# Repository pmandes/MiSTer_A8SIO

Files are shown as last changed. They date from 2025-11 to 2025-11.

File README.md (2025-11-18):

# MiSTer_A8SIO
Adapter for the SIO port to connect peripheral devices of the 8-bit Atari to the MiSTer FPGA.

## Interactive BOM: ##

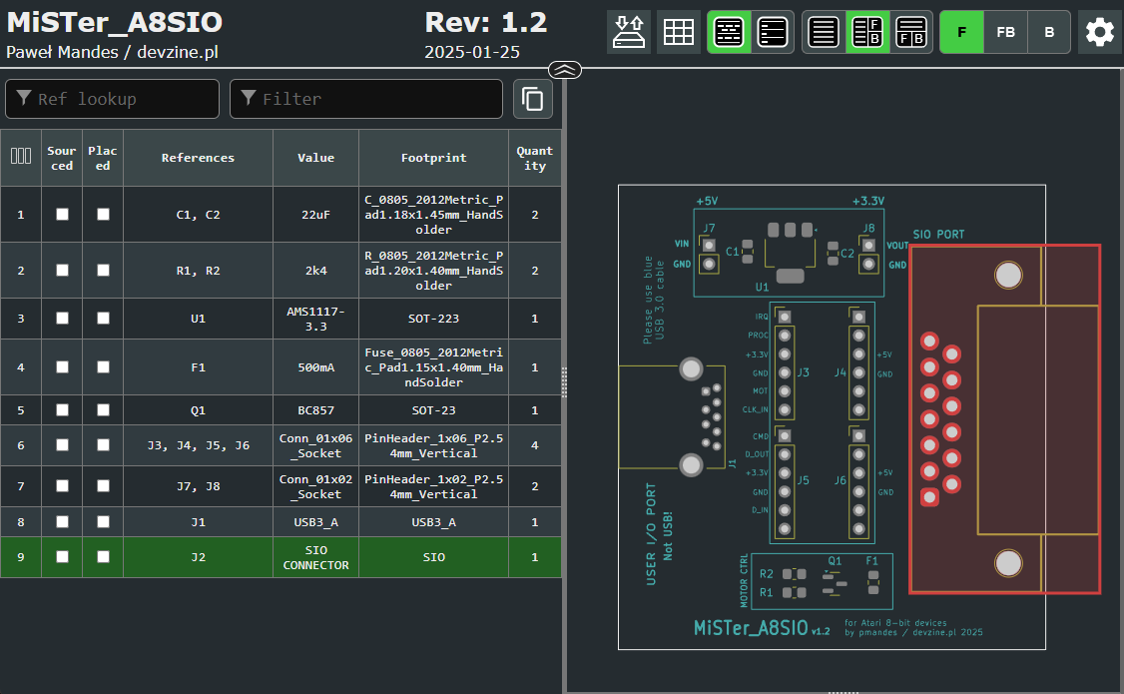
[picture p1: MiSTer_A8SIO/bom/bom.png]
<p align="center"></p>

## Components ##

The following modules can be used to build an adapter without using SMD components:

- AMS 1117 3.3V stabiliser module
- 2 x 4ch level shifter module
- USB 3.0 Type A angled socket
- SIO socket

<p align="center">
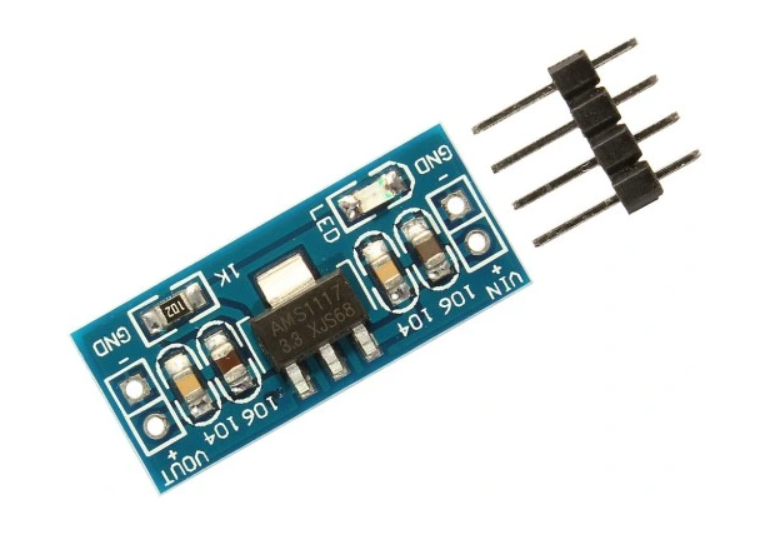
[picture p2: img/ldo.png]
  
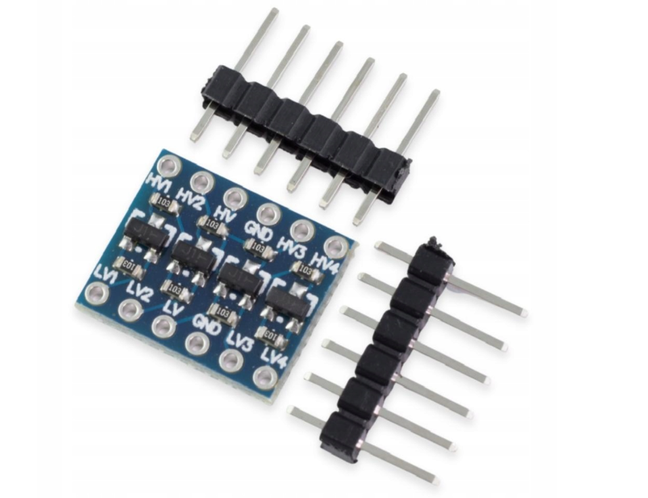
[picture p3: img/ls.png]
  
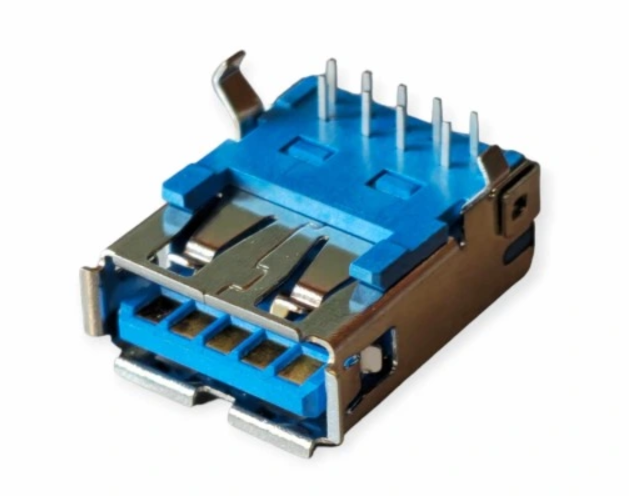
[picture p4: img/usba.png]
  
</p>

For basic functionality, one level shifter (mounted on J5/J6) and an LDO power supply module (mounted on J7/J8) are sufficient.

The MOTOR CTRL circuit for controlling the tape recorder is optional.

**To connect to MisterFPGA, you need a USB3.0 A data transfer cable (blue type A plugs on both sides).**

**The adapter can ONLY be connected to the User Port on the I/O daughter board.**

## Prototype ##

The prototype was tested with the following equipment:
- Atari 1050 Floppy disk drive
- FujiNet network adapter
- SDriveMAX drive emulator

<p align="center">
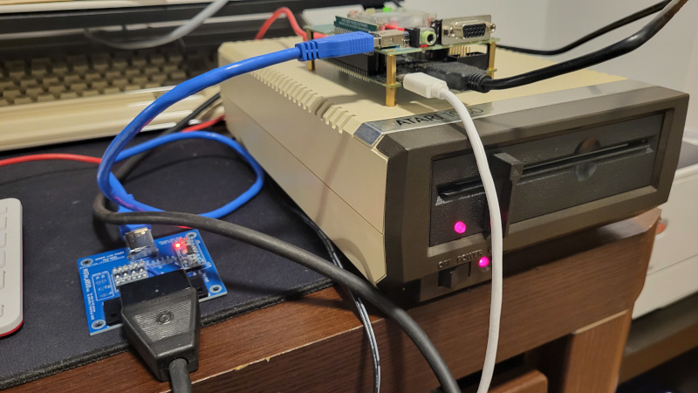
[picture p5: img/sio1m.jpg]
  
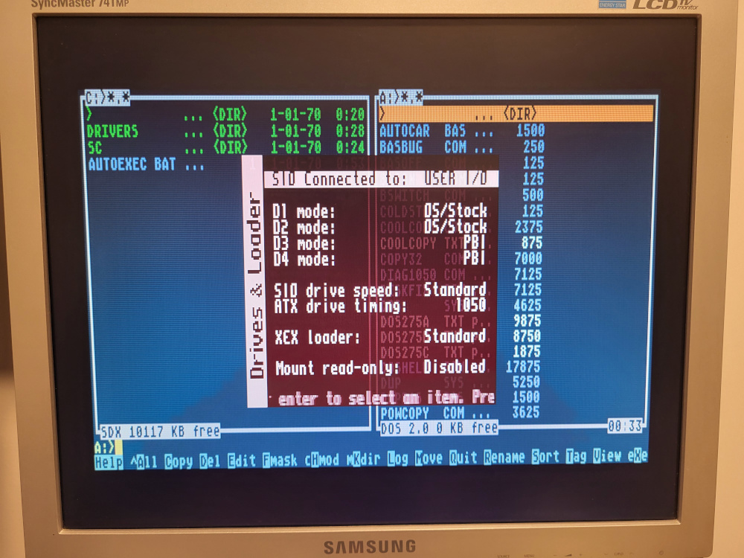
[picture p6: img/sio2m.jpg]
  
</p>
<p align="center">
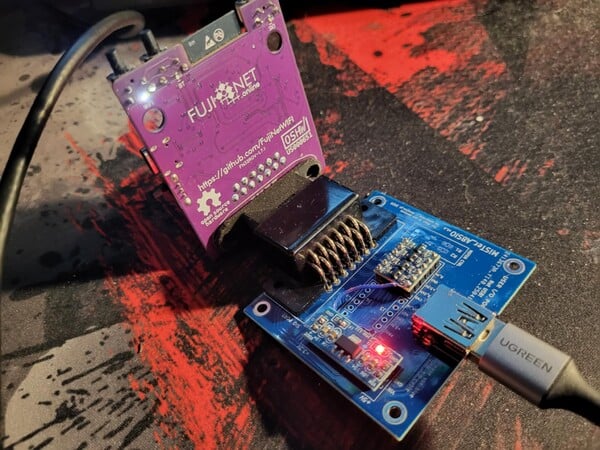
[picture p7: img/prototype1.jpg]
  
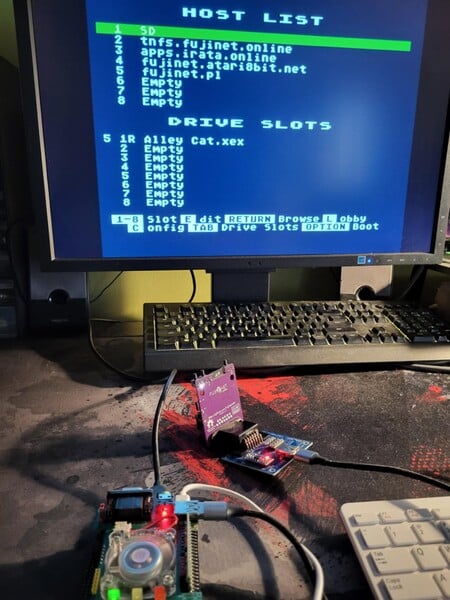
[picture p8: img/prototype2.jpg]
  
</p>

## Changleog: ##

**1.2**
- fix: crossed lines from USB3 A-A cable

**1.1**
- prototype / not published
- 2 * 4ch level shifters modules instead of HW221
  
**1.0**
- initial project

## PCB ##
Please consider supporting my open projects and order PCBs here:
https://www.pcbway.com/project/shareproject/MiSTer_A8SIO_a2581e8f.html

## Resources ##
New SIO sockets can be purchased here:
http://sikorsoft.waw.pl/hardware/gniazda-sio/

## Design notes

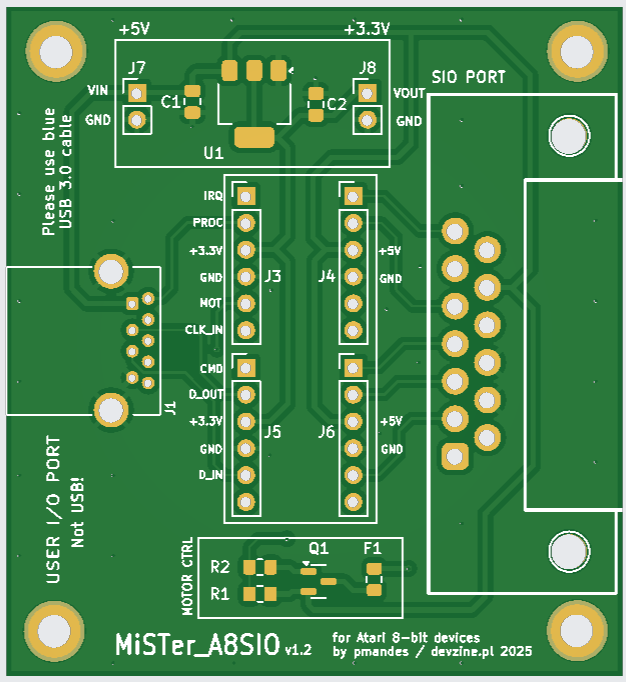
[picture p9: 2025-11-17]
img/sio1.png

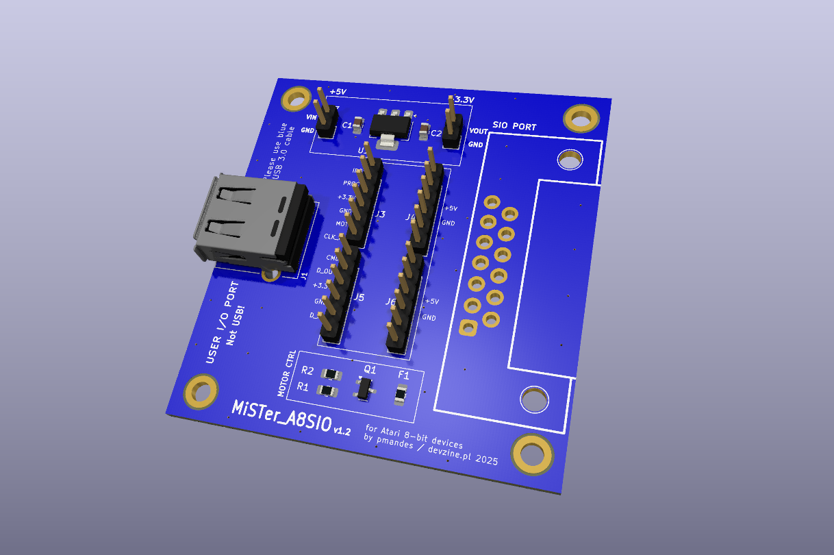
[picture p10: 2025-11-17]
img/siopcb.png

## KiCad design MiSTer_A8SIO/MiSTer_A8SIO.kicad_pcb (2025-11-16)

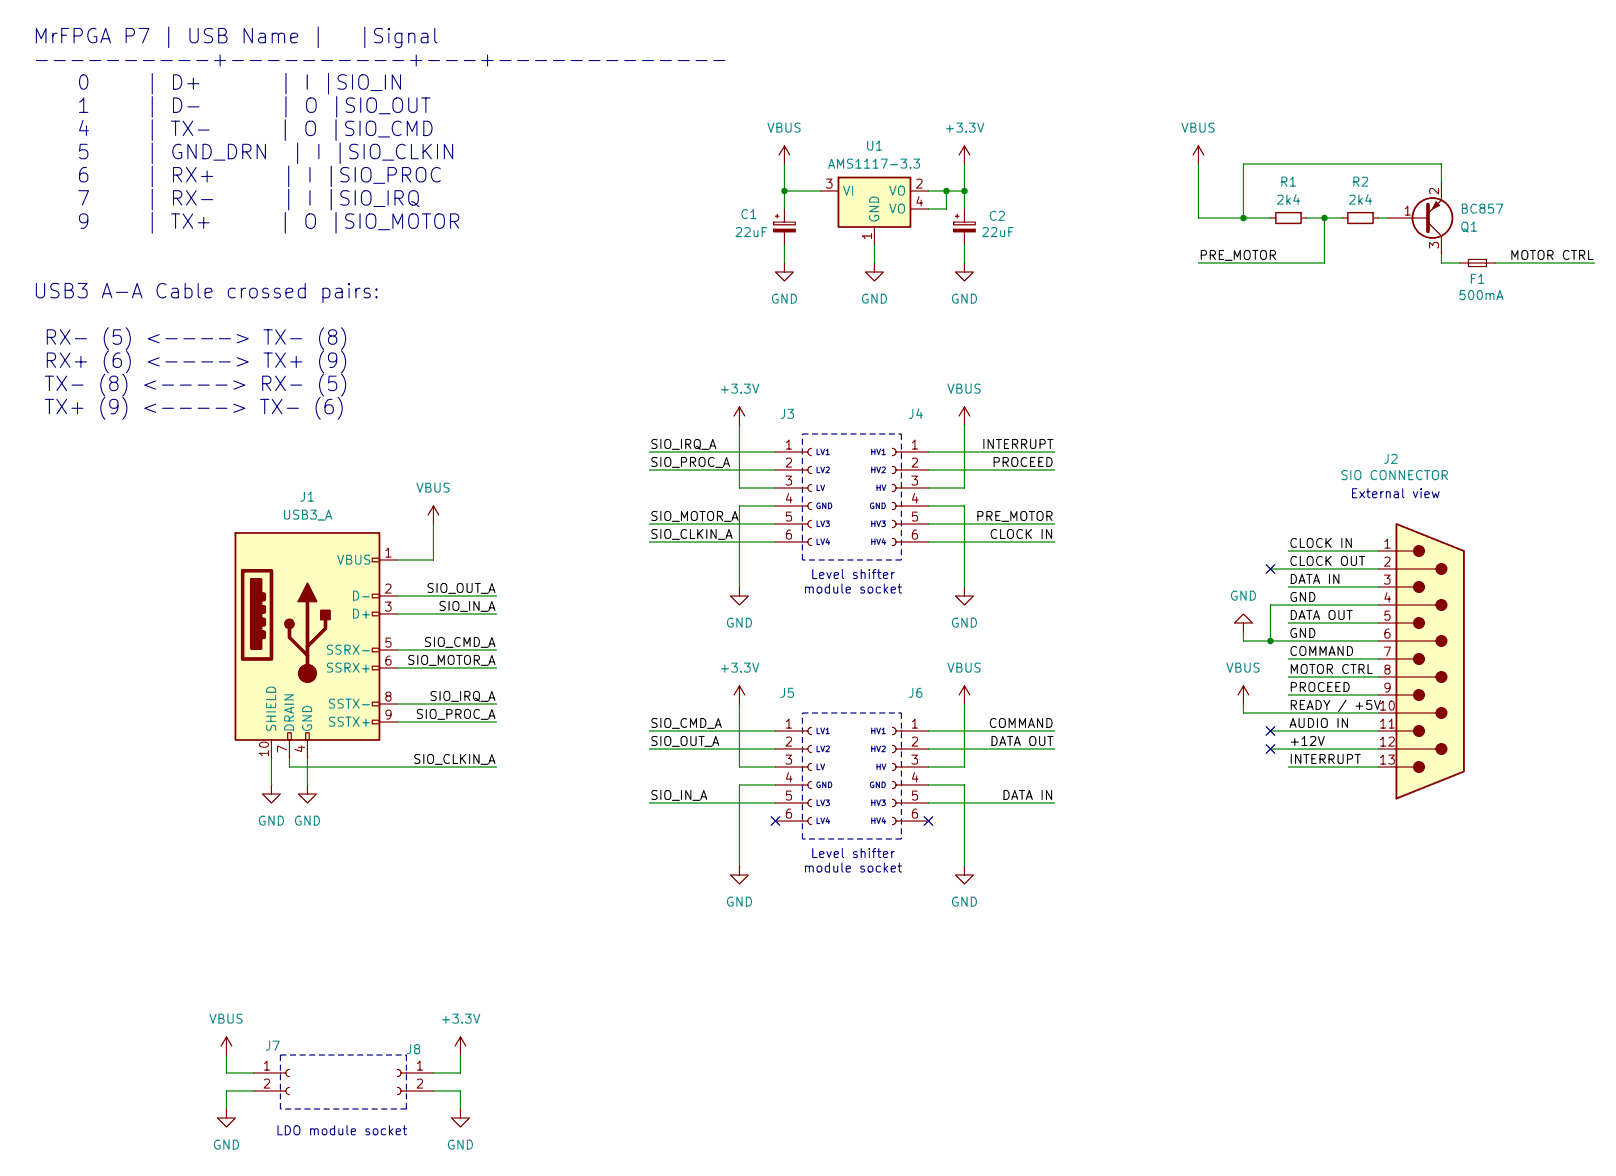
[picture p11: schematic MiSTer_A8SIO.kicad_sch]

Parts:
C1, C2: 22uF
F1: 500mA; Fuse_0805_2012Metric_Pad1.15x1.40mm_HandSolder
J1: USB3_A
J2: SIO CONNECTOR; SIO
J3, J4, J5, J6: Conn_01x06_Socket; PinHeader_1x06_P2.54mm_Vertical
J7, J8: Conn_01x02_Socket; PinHeader_1x02_P2.54mm_Vertical
Q1: BC857; SOT-23
R1, R2: 2k4; R_0805_2012Metric_Pad1.20x1.40mm_HandSolder
U1: AMS1117-3.3; SOT-223

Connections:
+3.3V: C2.1, J3.3, J5.3, J8.1, U1.2 (VO), U1.4 (VO)
/+12V: J2.12
/AUDIO IN: J2.11
/CLOCK IN: J2.1, J4.6
/CLOCK OUT: J2.2
/COMMAND: J2.7, J6.1
/DATA IN: J2.3, J6.5
/DATA OUT: J2.5, J6.2
/INTERRUPT: J2.13, J4.1
/MOTOR CTRL: F1.2, J2.8
/PRE_MOTOR: J4.5, R1.1, R2.2
/PROCEED: J2.9, J4.2
/SIO_CLKIN_A: J1.7 (DRAIN), J3.6
/SIO_CMD_A: J1.5 (SSRX-), J5.1
/SIO_IN_A: J1.3 (D+), J5.5
/SIO_IRQ_A: J1.8 (SSTX-), J3.1
/SIO_MOTOR_A: J1.6 (SSRX+), J3.5
/SIO_OUT_A: J1.2 (D-), J5.2
/SIO_PROC_A: J1.9 (SSTX+), J3.2
GND: C1.2, C2.2, J1.4 (GND), J1.10 (SHIELD), J2.4, J2.6, J3.4, J4.4, J5.4, J6.4, J7.2, J8.2, U1.1 (GND)
unnamed: Q1.1 (B), R2.1
unnamed: F1.1, Q1.3 (C)
VBUS: C1.1, J1.1 (VBUS), J2.10, J4.3, J6.3, J7.1, Q1.2 (E), R1.2, U1.3 (VI)

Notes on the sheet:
LDO module socket
External view
Level shifter module socket
HV1 HV2 HV GND HV3 HV4
LV1 LV2 LV GND LV3 LV4
MrFPGA P7 | USB Name | |Signal ----------+----------+---+------------- 0 | D+ | I |SIO_IN 1 | D- | O |SIO_OUT 4 | TX- | O |SIO_CMD 5 | GND_DRN | I |SIO_CLKIN 6 | RX+ | I |SIO_PROC 7 | RX- | I |SIO_IRQ 9 | TX+ | O |SIO_MOTOR USB3 A-A Cable crossed pairs: RX- (5) <----> TX- (8) RX+ (6) <----> TX+ (9)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

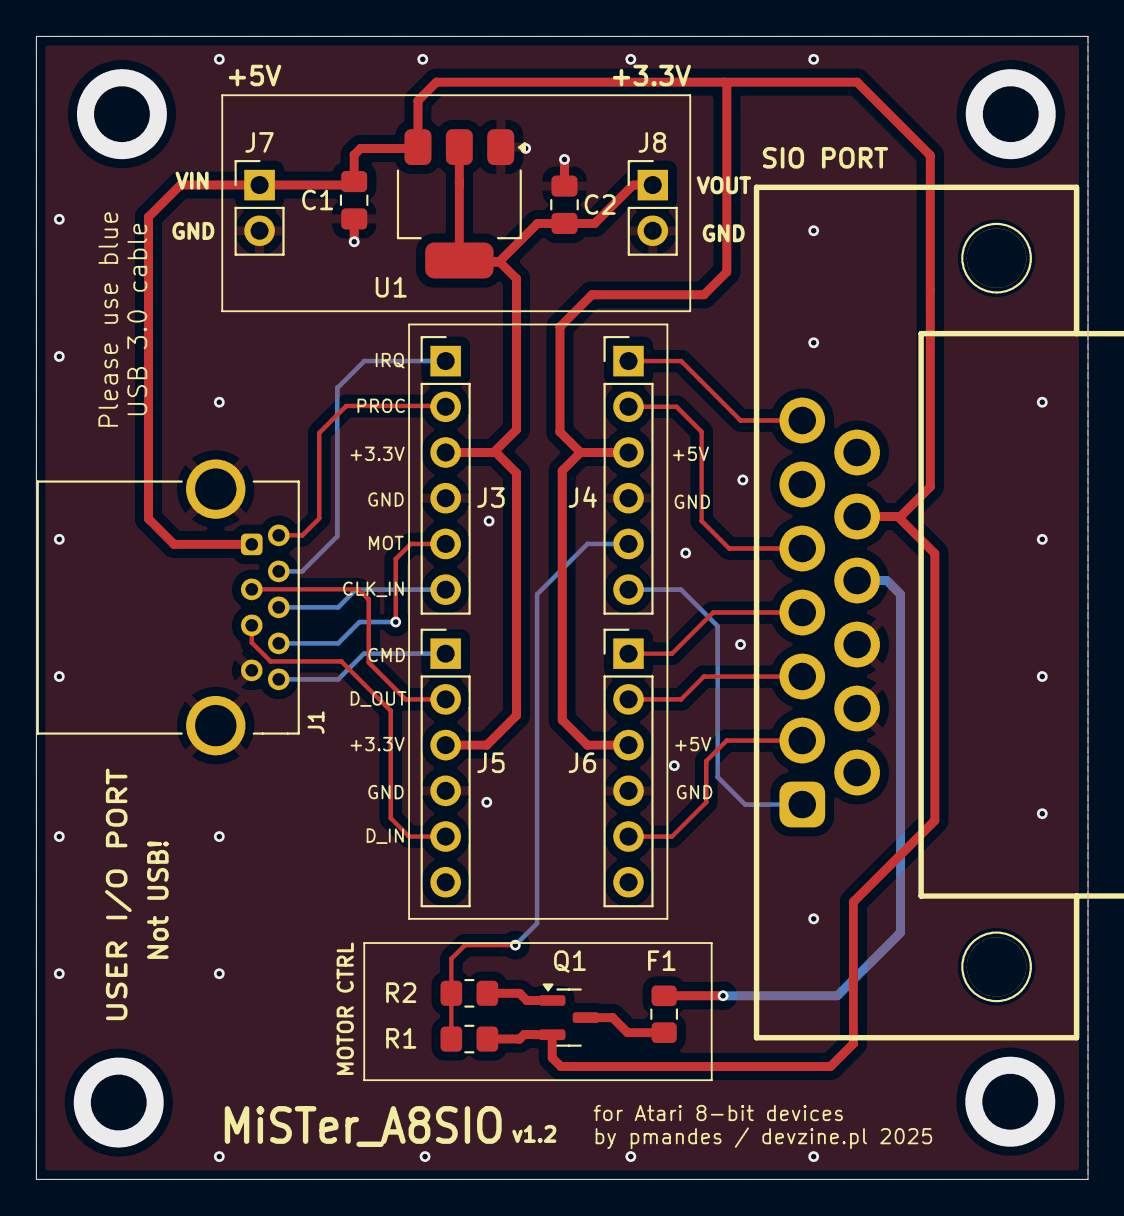
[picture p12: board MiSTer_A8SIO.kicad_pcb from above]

Board: 2 copper layers, 58.4 x 63.5 mm, 15 parts (0 on the bottom side), 20 nets.

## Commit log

2025-01-25 KiCad project ver 1.0
    [MiSTer_A8SIO.kicad_pcb, MiSTer_A8SIO.kicad_sch]
2025-11-16 Ver. 1.2, Fixed crossed lines
    [MiSTer_A8SIO-B_Cu.gbl, MiSTer_A8SIO-B_Mask.gbs, MiSTer_A8SIO-B_Paste.gbp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]
2025-11-16 BOM image
2025-11-16 Update README with interactive BOM and changelog
    Added an interactive BOM section and changelog to README.
2025-11-17 Update README with connection and prototype details
    Added information about USB3.0 A data transfer cable and prototype testing.
2025-11-17 Prototype images added.
2025-11-17 Add PCB support section to README
    Added a section for PCB support and ordering.
2025-11-17 PCB images added.
2025-11-17 Update image layout in README.md
    Rearranged image display in README and added prototype images.
2025-11-18 Reorganize SIO sockets information in README
    Moved SIO sockets purchase link to Resources section.
2025-11-26 Add link to 3D printed SIO socket project
